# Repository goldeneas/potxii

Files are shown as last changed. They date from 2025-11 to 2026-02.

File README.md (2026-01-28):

# Progetto PotXII

## Interfaccia
- Dashboard NodeRED
- MQTT/Wifi
- Diagramma di linea per ogni grandezza misurata
- Grafico per indicare il livello dell'acqua nel tempo
- Log per eventi eccezionali
- Soglia umidita' per irrigazione
- Livello luminosita' dei LED regolabile
- Attivazione manuale pompa

## Sensori/Componenti Utilizzati
- Pompa ad immersione con rele'
- HCSR04
- Sensore per umidita' del terreno
- TSL2561
- SSD1306
- DHT
- Power supply esterno
- LED con PWM
- Pulsante per reset
- MB102

## Features
- Start at boot
- Notifica dashboard serbatoio vuoto
- Misurazione umidità terreno ed aria, luminosità e temperatura aria
- Analisi delle grandezze misurate
- Irrigazione automatica
- Illuminazione con LED

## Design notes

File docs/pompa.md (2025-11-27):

1. Il Circuito di Potenza (Batteria e Pompa)
Questo è il circuito che fa girare effettivamente l'acqua. Qui passa la corrente alta.

Usa le 3 viti (morsetti) del relè. Ignora "NC" (Normally Closed), useremo "NO" (Normally Open) perché vuoi che la pompa stia spenta finché non dai il comando.

    Batteria (+) [Positivo]: Collegalo al morsetto centrale COM del relè.

    Relè NO [Normally Open]: Collega qui il filo ROSSO del motore.

    Batteria (-) [Negativo]: Collega qui direttamente il filo NERO del motore.

Cosa succede fisicamente: La corrente parte dalla batteria, arriva al morsetto COM, si ferma perché l'interruttore è aperto. Quando il relè scatta, il contatto si chiude verso NO, la corrente fluisce nel filo rosso, attraversa il motore e torna alla batteria col filo nero.

2. Il Circuito di Controllo (I 3 Pin)

Qui è dove rischi di fare danni se non sai cosa stai facendo. Questi tre pin servono per dire al relè "accenditi".

    VCC: Qui devi dare l'alimentazione per la bobina del relè.

        Attenzione: Leggi cosa c'è scritto sul relè (es. 5V o 12V). Se il relè è da 5V e gli dai 12V dalla batteria della pompa, lo bruci. Se il relè è da 12V e la batteria è da 12V, puoi collegarlo al positivo della batteria.

    GND: Va al negativo (Ground) della batteria o del microcontrollore.

    IN: Questo è il segnale. Per accendere la pompa, questo pin deve ricevere un segnale (solitamente 5V o 3.3V se usi Arduino, oppure collegato a GND o VCC a seconda se il relè è "Low Trigger" o "High Trigger").

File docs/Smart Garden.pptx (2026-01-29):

## Smart Garden

Gruppo 12

## SMART POT-XII

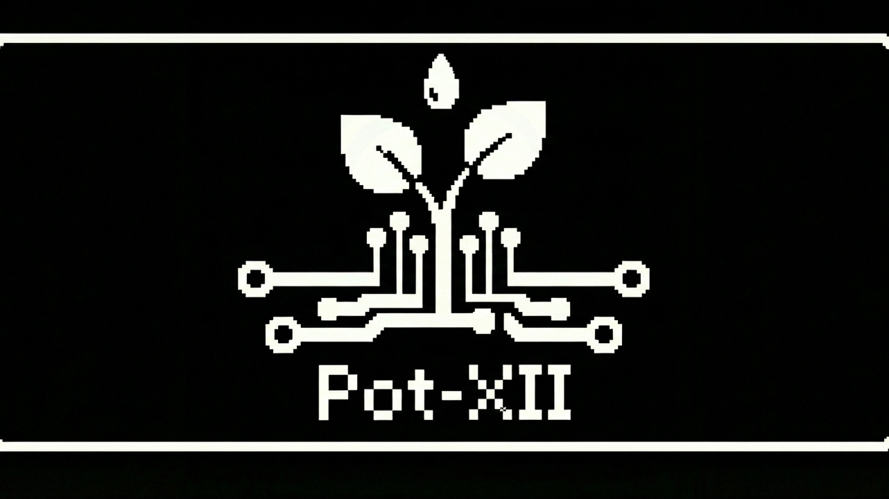
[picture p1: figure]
Immagine che contiene testo, Carattere, logo, simbolo Il contenuto generato dall'IA potrebbe non essere corretto.

Un sistema intelligente progettato per la cura automatizzata delle piante domestiche. Smart Pot-XII trasforma un normale vaso in un ecosistema monitorato.

Salute della pianta al primo posto
Tecnologia ESP32 integrata
Irrigazione automatica basata sui d

## SENSORE UMIDITA’ DEL TERRENO

Il sensore di umidità del terreno lavora insieme ad un Comparatore di tensione (quello blu).
La sonda a forma di forca, cioè il sensore, viene inserita nel terreno e invia un segnale di resistenza variabile al Comparatore di Tensione il quale lo trasforma in una tensione compresa tra 0V e 3,3V.
Quindi all'ESP32 arriva un segnale analogico (la tensione) attraverso il pin A0.
Dato che l’SP32 usa solo il linguaggio digitale, colleghiamo il pin A0 del Comparatore ad un pin ADC dell‘Espe32.
L’esp32 leggerà la tensione è la tradurrà in valori compresi tra 0 (massima umidità) e 4095(terreno secco)

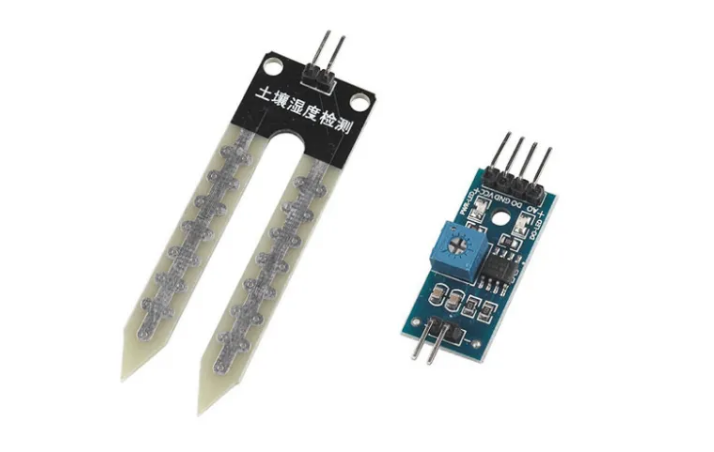
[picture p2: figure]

## SENSORE DELLA LUMINOSITA’

Il TSL2561 è un sensore digitale di luminosità.
Ha 4 pin: VCC (3.3V), GND, SCL, SDA.
Il TSL2561 comunica tramite il protocollo I2C, che richiede due pin fondamentali:
SCL (Serial Clock): È il segnale di clock che sincronizza la trasmissione dei dati.
SDA (Serial Data): È il pin su cui viaggiano fisicamente i dati digitali della luminosità.

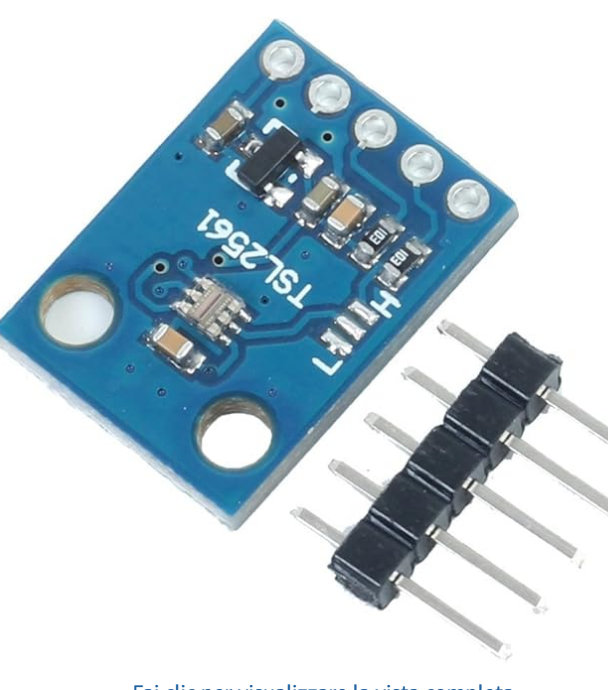
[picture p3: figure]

## SENSORE AD ULTRASUONI

Il Sensore di distanza ad ultrasuoni HCSR04
Ha 4 pin: VCC(3.3V), TRIG, ECHO, GND
La comunicazione con questo sensore avviene
attraverso un driver. Quando il pin TRIG e' alto, il sensore invia un segnale ad ultrasuoni a 40Hz; quando il segnale rimbalza su un oggetto e colpisce il sensore, il pin ECHO viene messo alto per il tempo di volo del segnale.
La formula per la conversione in distanza usa la velocita' del suono nell'aria (340 m/s):
distanza = tempo[s] * 340[m/s] / 2

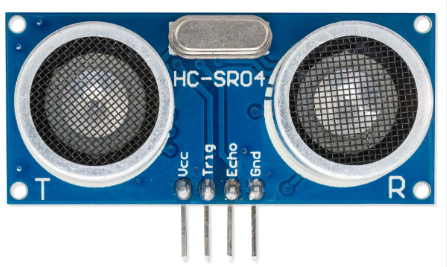
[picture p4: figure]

## POMPA

La pompa ad immersione
Viene utilizzata con una fonte di alimentazione esterna e con un rele'
Il rele' fornisce tre pin da collegare: VCC, GND e IN.
Possiamo attivare la pompa mantenendo alto il pin IN per il tempo richiesto.
Per il corretto funzionamento bisogna collegare la porta COM con l'alimentazione della pompa, e la porta NO (Normally Open) con l'alimentazione esterna.

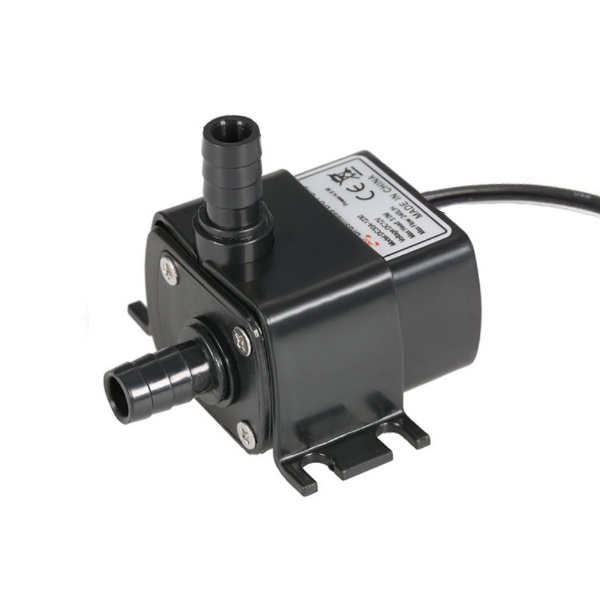
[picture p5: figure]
Mini pompa ad immersione 12 Vdc
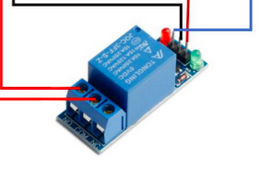
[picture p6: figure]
Immagine che contiene Componente di circuito, Ingegneria elettronica, Componente elettrico, Componente di circuito passivo Il contenuto generato dall&#39;IA potrebbe non essere corretto.

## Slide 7

DASHBOARD NODERED

La dashboard rappresenta il centro di controllo operativo permette di visualizzare i dati in tempo reale provenienti dall'ESP32 tramite l’utilizzo del protocollo MQTT.
Visualizzazione immediata della temperatura e dell’umidità dell'aria, dell’umidità del suolo, dell’esposizione alla luce e del livello del serbatoio.

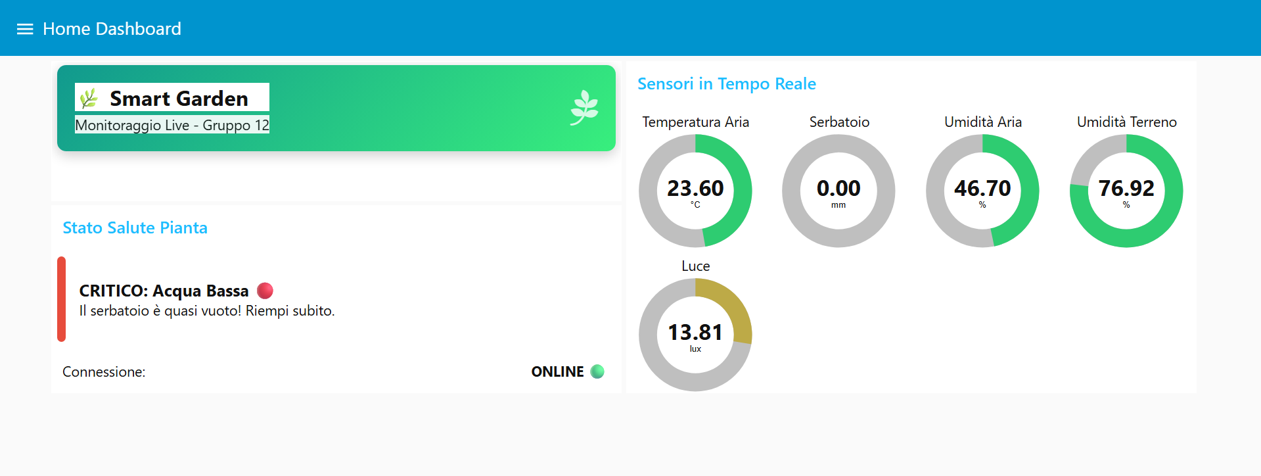
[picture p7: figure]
Immagine che contiene testo, schermata, Carattere, software Il contenuto generato dall'IA potrebbe non essere corretto.

Homepage

## DASHBOARD NODERED

Tramite la dashboard è possibile

Monitorare i grafici; diagrammi dedicati ad ogni grandezza fisica misurata
Gestire il serbatoio; prevedere quando bisogna riempire il serbatoio, attivare manualmente la pompa o impostare una soglia d’umidità per l’irrigazione automatica
Monitorare i log; registro per tracciare eventi particolare (attivazione pompa o livello d’acqua nel serbatoio)
Compensare la scarsa luce naturale (simulazione); slider per regolare l'intensità dei LED tramite PWM

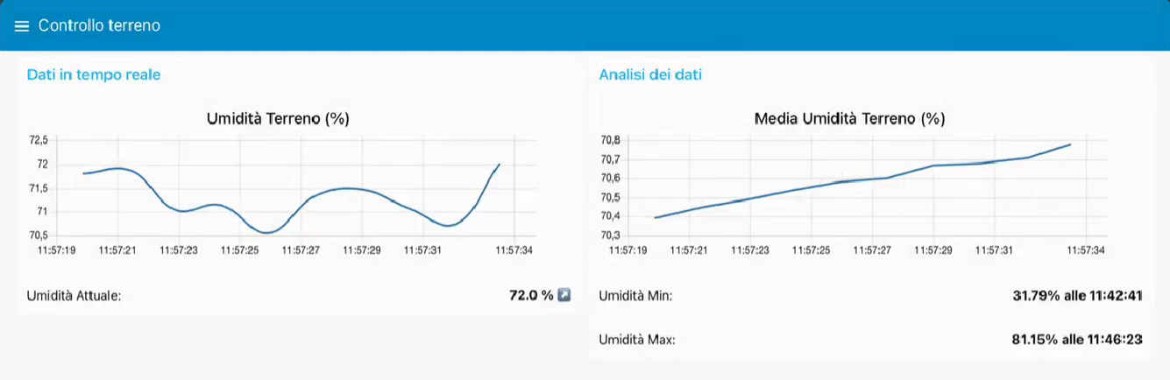
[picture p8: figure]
Immagine che contiene testo, schermata, linea, Diagramma Il contenuto generato dall'IA potrebbe non essere corretto.

Grafici in tempo reale

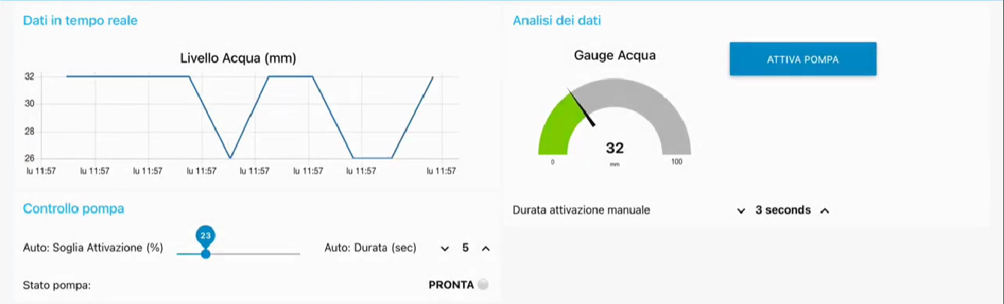
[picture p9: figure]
Immagine che contiene testo, diagramma, schermata, Carattere Il contenuto generato dall'IA potrebbe non essere corretto.

Gestione serbatoio

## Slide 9

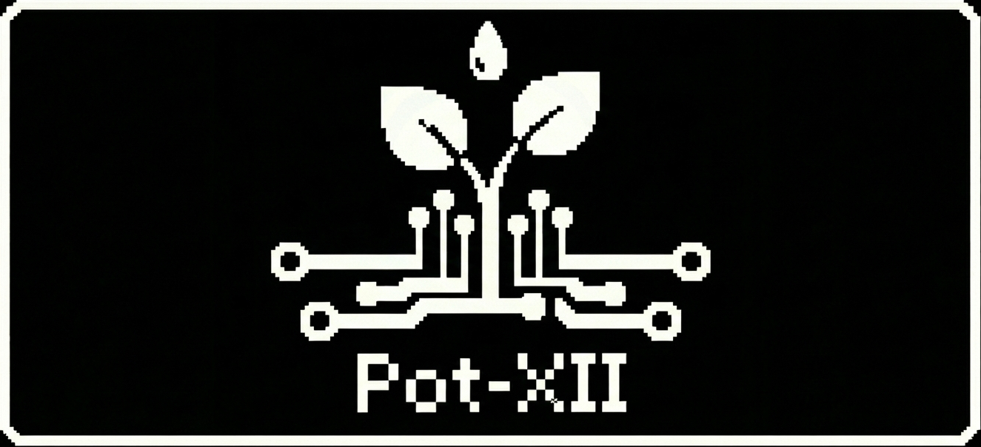
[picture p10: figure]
Immagine che contiene testo, Carattere, logo, simbolo Il contenuto generato dall'IA potrebbe non essere corretto.

Lisena Nicolò Massimo
Mancini Sofia
Picarella Nicola

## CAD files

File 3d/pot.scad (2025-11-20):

pot_width = 20;
pot_depth = 20;
pot_height = 10;

tank_width = 10;
tank_depth = 10;
tank_height = 10;

module hexagon() {
	cylinder(r=10, h=5, $fn=6);
}

module pot(position, dimensions) {
    diff_position = [for (i = position) i + 1];
        
    diff_dimensions = [
        for (i = [0 : 2])
            if(i == 2) dimensions[i]
            else dimensions[i] - 2
    ];
    
    difference () {
        translate(position) {
            cube(dimensions);
        }
        
        translate(diff_position) {
            cube(diff_dimensions);
        }
    }
}

module tank(position, dimensions) {
    translate([20, 10, 0]) {
        difference () {
            cylinder(7, 10, 10);
            translate([-10, 0, 9]) {
                cube(20, center = true);
            };
            translate ([0, 0, 1]) {
                cylinder(11, 9, 9);
            }
        }
    } 
}

module esp_container() {
    pot([0, pot_depth - 8, 0], [20, 8, 20]);
}

module holes() {
    translate([19.5, 15, 16]) {
        rotate([0, 90, 0]) {
            sphere(1.5);
        }
    }
	
	translate([8.5, 18.5, 15]) {
		cube([2.174, 1.806, 2]);
	}
	
	translate([13, 12.3, 15]) {
        rotate([0, 90, 0]) {
            sphere(1.5);
        }
    }
}

module lid() {
    union() {
        color ("red", 1.0) {
            translate ([0, 12, 30]) {
                cube([20, 8, 1]);
            }
        }
    
        color ("blue", 1.0) {
            translate ([1, 13, 29.5]) {
                cube([18, 6, 1]);
            }
        }
    }
}

module esp_plane() {
    translate([0, 12, 10]) {
		cube([20, 7, 1]);
    }
}

union () {
    difference() {
        tank([pot_width - 0.9, 5, 0], [tank_width, tank_depth, tank_height]);
        holes();
    }
    
    difference() {
        esp_container();
        holes();
    }
    
    difference() {
        pot([0, 0, 0], [pot_width, pot_depth, pot_height]);
        holes();
    }
	
	difference() {
        esp_plane();
        holes();
    }
}

lid();
 

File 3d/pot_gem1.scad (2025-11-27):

// ==============================================================================
// PROGETTO: All-in-One Smart Vase (ESP32 IoT)
// VERSIONE: 1.0.0
// MATERIALE CONSIGLIATO: PETG o ASA (Impermeabile, resistente UV)
// NOTE DI STAMPA: 
// - Pareti: Almeno 3 perimetri per impermeabilità.
// - Infill: 20% Gyroid.
// - Supporti: Minimi necessari solo per la finestra OLED o i passaggi cavi.
// ==============================================================================

// --- PARAMETRI GENERALI ---
$fn = 60; // Risoluzione curve (aumentare per export finale)
wall_thick = 3.0; // Spessore pareti (robusto per tenuta stagna)
tolerance = 0.4;  // Tolleranza per parti a incastro (vassoio)

// --- DIMENSIONI VASO ---
vase_width = 140;
vase_depth = 140;
vase_height = 150;
corner_radius = 10;

// --- DIMENSIONI ELETTRONICA ---
oled_width = 27;  // Larghezza modulo OLED 0.96
oled_height = 27; // Altezza modulo OLED (approssimativa del PCB)
oled_screen_w = 23; // Larghezza solo schermo
oled_screen_h = 12; // Altezza solo schermo
esp32_bay_depth = 30; // Profondità vano elettronica

// --- CONFIGURAZIONE RENDERING ---
// Imposta a 1 per vedere il vaso, 0 per nasconderlo
show_main_body = 1;
// Imposta a 1 per vedere il vassoio di drenaggio, 0 per nasconderlo
show_drainage_tray = 1;
// Imposta a 1 per vedere il coperchio elettronica (da stampare piatto), 0 nascondi
show_lid = 0; 


// ==============================================================================
// LOGICA DI COSTRUZIONE
// ==============================================================================

module rounded_cube(size, r) {
    hull() {
        translate([r, r, 0]) cylinder(h=size[2], r=r);
        translate([size[0]-r, r, 0]) cylinder(h=size[2], r=r);
        translate([size[0]-r, size[1]-r, 0]) cylinder(h=size[2], r=r);
        translate([r, size[1]-r, 0]) cylinder(h=size[2], r=r);
    }
}

module main_body() {
    difference() {
        // 1. CORPO SOLIDO ESTERNO
        rounded_cube([vase_width, vase_depth, vase_height], corner_radius);

        // 2. SCAVO COMPARTO SUOLO (Retro Sinistra - occupa 60% volume)
        // Lasciamo spazio sotto per il vassoio di drenaggio (altezza 20mm)
        translate([wall_thick, wall_thick, 25]) 
            cube([vase_width - wall_thick*2, vase_depth*0.65, vase_height]);

        // 3. SCAVO SERBATOIO ACQUA (Retro Destra/Laterale)
        // Isolato dal suolo tramite parete
        // In questo design, mettiamo l'acqua DIETRO il suolo o A LATO.
        // Facciamo una "L" shape o dividiamo: Suolo Davanti, Acqua Dietro?
        // Meglio: Suolo occupa 2/3 posteriori, Acqua e Elettronica davanti.
        
        // RIDEFINIZIONE LAYOUT INTERNO PER SEMPLICITÀ E ROBUSTEZZA:
        // A: SUOLO -> Grande rettangolo posteriore
        // B: ACQUA -> Cilindro/Rettangolo anteriore sinistro
        // C: ELETTRONICA -> Rettangolo anteriore destro
        
        // RESET SCAVI PRECEDENTI, PROCEDIAMO CON NUOVO LAYOUT
    }
}

// Ricostruzione con layout a blocchi per massima chiarezza
module smart_vase_final() {
    
    water_tank_width = (vase_width / 2) - wall_thick;
    electronics_width = (vase_width / 2) - wall_thick;
    front_compartment_depth = 40; 
    soil_depth = vase_depth - front_compartment_depth - (wall_thick * 3);
    tray_height = 20;
    floor_z = tray_height + wall_thick + 2; // Altezza pavimento comparti superiori

    difference() {
        // --- POSITIVO: Guscio Esterno ---
        rounded_cube([vase_width, vase_depth, vase_height], corner_radius);

        // --- NEGATIVO: Comparto SUOLO (A) ---
        // Occupa la parte posteriore
        translate([wall_thick, front_compartment_depth + wall_thick*2, floor_z])
            rounded_cube([
                vase_width - wall_thick*2, 
                soil_depth, 
                vase_height // Va fino in cima
            ], 5);

        // --- NEGATIVO: Comparto ACQUA (B) ---
        // Anteriore Sinistro
        translate([wall_thick, wall_thick, floor_z])
            cube([
                water_tank_width - wall_thick, 
                front_compartment_depth, 
                vase_height
            ]);

        // --- NEGATIVO: Comparto ELETTRONICA (C) ---
        // Anteriore Destro
        translate([water_tank_width + wall_thick*2, wall_thick, floor_z])
            cube([
                electronics_width - wall_thick, 
                front_compartment_depth, 
                vase_height
            ]);

        // --- NEGATIVO: Vano Vassoio Drenaggio (D) ---
        // Scavo passante sul fondo (solo posteriore sotto il suolo)
        translate([wall_thick, front_compartment_depth + wall_thick*2, wall_thick])
            cube([
                vase_width - wall_thick*2, 
                soil_depth + 10, // Un po' più lungo per estrazione
                tray_height
            ]);
            
        // --- DETTAGLI FUNZIONALI ---
        
        // 1. Fori di drenaggio (Suolo -> Vassoio)
        for(x = [20 : 15 : vase_width-20]) {
            for(y = [front_compartment_depth + 30 : 15 : vase_depth-20]) {
                translate([x, y, floor_z - 5])
                    cylinder(h=10, r=2); // Fori da 4mm
            }
        }

        // 2. Finestra OLED (Nel comparto Elettronica)
        translate([water_tank_width + wall_thick*2 + (electronics_width/2), -1, vase_height - 40]) {
            // Foro schermo passante
            cube([oled_screen_w, 10, oled_screen_h], center=true);
            // Scasso interno per il PCB (non passante)
            translate([0, 3, 0])
                cube([oled_width, 5, oled_height], center=true);
        }
        
        // 3. Passaggi Cavi (Cavidotti interni)
        // Elettronica -> Suolo (per sensori)
        translate([water_tank_width + wall_thick*2 + (electronics_width/2), front_compartment_depth - 5, vase_height - 20])
            rotate([90, 0, 0])
            cylinder(h=20, r=4); // Foro 8mm inclinato verso il suolo

        // Elettronica -> Acqua (per pompa)
        // Foro nel muro divisorio centrale
        translate([water_tank_width + wall_thick/2 + 1, front_compartment_depth/2, 40])
            rotate([0, 90, 0])
            cylinder(h=10, r=3, center=true);
            
        // 4. Foro USB (lato elettronica o fondo)
        translate([vase_width - 10, front_compartment_depth/2, floor_z + 10])
            rotate([0, 90, 0])
            cylinder(h=20, r=4); // Accesso cavo alimentazione laterale
    }
}

module drainage_tray() {
    tray_w = vase_width - wall_thick*2 - tolerance;
    front_compartment_depth = 40; 
    soil_depth = vase_depth - front_compartment_depth - (wall_thick * 3);
    tray_d = soil_depth;
    tray_h = 18;

    difference() {
        // Corpo vassoio
        cube([tray_w, tray_d, tray_h]);
        // Scavo interno vassoio
        translate([wall_thick, wall_thick, wall_thick])
            cube([tray_w - wall_thick*2, tray_d - wall_thick, tray_h]);
    }
    
    // Maniglia estrazione
    translate([tray_w/2, 0, tray_h/2])
        rotate([90,0,0])
        cylinder(h=5, r1=5, r2=8);
}

module electronics_lid() {
    // Semplice coperchio per chiudere sopra se necessario, 
    // anche se il design è open top per il suolo.
    // Creiamo un tappo solo per il vano elettronica per proteggerlo dagli schizzi
    
    water_tank_width = (vase_width / 2) - wall_thick;
    electronics_width = (vase_width / 2) - wall_thick;
    front_compartment_depth = 40; 
    
    cube([electronics_width - wall_thick - tolerance, front_compartment_depth - tolerance, 2]);
}

// ==============================================================================
// GENERAZIONE SCENA
// ==============================================================================

if (show_main_body) {
    color("Teal") 
    smart_vase_final();
}

if (show_drainage_tray) {
    front_compartment_depth = 40; 
    // Posizioniamo il vassoio nel suo alloggiamento
    color("Silver")
    translate([wall_thick + tolerance/2, front_compartment_depth + wall_thick*2, wall_thick])
        drainage_tray();
}

if (show_lid) {
    water_tank_width = (vase_width / 2) - wall_thick;
    // Posizionato sopra l'elettronica
    color("DarkSlateGray")
    translate([water_tank_width + wall_thick*2 + tolerance/2, wall_thick + tolerance/2, vase_height])
        electronics_lid();
}
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

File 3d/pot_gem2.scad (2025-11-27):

// ==============================================================================
// PROGETTO: All-in-One Smart Vase (ESP32 IoT)
// VERSIONE: 1.4.0 (Water Level Sensor Correction)
// ==============================================================================

// --- PARAMETRI GENERALI ---
$fn = 60;
wall_thick = 3.0; 
tolerance = 0.5; 

// --- DIMENSIONI VASO ---
vase_width = 200;
vase_depth = 200;
vase_height = 180;
corner_radius = 10;

// --- DIMENSIONI ELETTRONICA / COMPARTI ANTERIORI ---
oled_width = 24;  
oled_height = 16; 
oled_screen_w = oled_width; 
oled_screen_h = oled_height; 

esp32_bay_depth = 100; 

// --- CONFIGURAZIONE NUOVA: PAVIMENTO ELETTRONICA ---
electronics_floor_z = 80; 

inner_corner_radius = 6;

// --- CONFIGURAZIONE RENDERING ---
show_main_body = 1;
show_drainage_tray = 1;
show_lid = 0; 
show_sensor = 1; 

// ==============================================================================
// LOGICA DI COSTRUZIONE
// ==============================================================================

module lid_generic(w, d) {
    lid_h = 2;
    lid_r = max(1, inner_corner_radius - tolerance); 
    
    union() {
        rounded_cube([w, d, lid_h], lid_r);
        translate([w/2, d/2, lid_h])
            cylinder(h=5, r1=4, r2=6);
    }
}

module rounded_cube(size, r) {
    hull() {
        translate([r, r, 0]) cylinder(h=size[2], r=r);
        translate([size[0]-r, r, 0]) cylinder(h=size[2], r=r);
        translate([size[0]-r, size[1]-r, 0]) cylinder(h=size[2], r=r);
        translate([r, size[1]-r, 0]) cylinder(h=size[2], r=r);
    }
}

module smart_vase_final() {
    
    water_tank_width = (vase_width / 2) - wall_thick;
    electronics_width = (vase_width / 2) - wall_thick;
    
    front_compartment_depth = esp32_bay_depth; 
    
    soil_depth = vase_depth - front_compartment_depth - (wall_thick * 3);
    tray_height = 20;
    floor_z = tray_height + wall_thick + 2; 

    difference() {
        // --- POSITIVO: Guscio Esterno ---
        rounded_cube([vase_width, vase_depth, vase_height], corner_radius);

        // --- NEGATIVO: Comparto SUOLO (A) ---
        translate([wall_thick, front_compartment_depth + wall_thick*2, floor_z])
            rounded_cube([
                vase_width - wall_thick*2, 
                soil_depth, 
                vase_height 
            ], 5);

        // --- NEGATIVO: Comparto ACQUA (B) ---
        translate([wall_thick, wall_thick, floor_z])
            rounded_cube([
                water_tank_width - wall_thick, 
                front_compartment_depth, 
                vase_height
            ], inner_corner_radius);

        // --- NEGATIVO: Comparto ELETTRONICA (C) ---
        translate([water_tank_width + wall_thick*2, wall_thick, electronics_floor_z])
            rounded_cube([
                electronics_width - wall_thick, 
                front_compartment_depth, 
                vase_height 
            ], inner_corner_radius);

        // --- NEGATIVO: Vano Vassoio Drenaggio (D) ---
        translate([wall_thick, front_compartment_depth + wall_thick*2, wall_thick])
            rounded_cube([
                vase_width - wall_thick*2, 
                soil_depth + 20, 
                tray_height
            ], inner_corner_radius);
            
        // --- DETTAGLI FUNZIONALI ---
        
        // 1. Fori di drenaggio
        for(x = [20 : 20 : vase_width-20]) {
            for(y = [front_compartment_depth + 30 : 20 : vase_depth-20]) {
                translate([x, y, floor_z - 5])
                    cylinder(h=10, r=2.5); 
            }
        }

        // 2. Finestra OLED
        translate([water_tank_width + wall_thick*2 + (electronics_width/2), -1, vase_height - 40]) {
            cube([oled_screen_w, 10, oled_screen_h], center=true);
            translate([0, 3, 0])
                cube([oled_width, 5, oled_height], center=true);
        }
        
        // 3. Passaggi Cavi
        // Elettronica -> Suolo
        translate([water_tank_width + wall_thick*2 + (electronics_width/2) - 15, front_compartment_depth - 5, vase_height - 25])
            rotate([-90, 0, 0]) 
            cylinder(h=25, r=10); 

        // Elettronica -> Acqua (Sensore Livello / Pompa)
        // Questo foro collega la parte alta del serbatoio con la parte alta dell'elettronica
        translate([water_tank_width + wall_thick*1.5, front_compartment_depth/2, vase_height - 20])
            rotate([0, 90, 0])
            cylinder(h=wall_thick*4, r=10, center=true);
            
        // 4. Foro USB 
        translate([vase_width - 10, front_compartment_depth/2, electronics_floor_z + 15])
            rotate([0, 90, 0])
            cylinder(h=20, r=10); 
            
        // 5. Foro Tubo Acqua
        translate([water_tank_width + wall_thick*2 + (electronics_width/2) + 15, front_compartment_depth - 5, vase_height - 25])
            rotate([-90, 0, 0])
            cylinder(h=25, r=10);
    }
}

module drainage_tray() {
    front_compartment_depth = esp32_bay_depth; 
    
    tray_w = vase_width - wall_thick*2 - tolerance;
    soil_depth_actual = vase_depth - front_compartment_depth - (wall_thick * 2); 
    tray_d = soil_depth_actual - 5; 
    tray_h = 20 - tolerance; 

    difference() {
        cube([tray_w, tray_d, tray_h]);
        translate([wall_thick, wall_thick, wall_thick])
            cube([tray_w - wall_thick*2, tray_d - wall_thick*2, tray_h + 10]);
    }
    
    translate([tray_w/2, 0, tray_h/2]) {
        difference() {
            union() {
                translate([0, -2, 0]) cube([30, 4, tray_h], center=true);
                rotate([90,0,0]) cylinder(h=2, r=8);
            }
            rotate([90,0,0]) cylinder(h=10, r=4, center=true);
        }
    }
}

module electronics_lid() {
    water_tank_width = (vase_width / 2) - wall_thick;
    electronics_width = (vase_width / 2) - wall_thick;
    front_compartment_depth = esp32_bay_depth; 
    
    cube([electronics_width - wall_thick - tolerance, front_compartment_depth - tolerance, 2]);
}

module us_support() {
    // Dimensioni standard HC-SR04 approssimative
    us_pcb_w = 45; 
    us_pcb_h = 20;
    
    holder_w = esp32_bay_depth;
    holder_d = 10; 
    holder_h = 40; // Leggermente più compatto
    
    holes_radius = 8.2;
	
	rotate([90, 0, 90]) {
		translate([-37.5, 30, -17]) {
			translate([0, -10, holder_h - 5]) {
				cube([esp32_bay_depth, 10, 5]);
			}

			difference() {
				// Corpo principale
				cube([holder_w, holder_d, holder_h]);
				
				// Scasso PCB
				translate([(holder_w - us_pcb_w)/2, 2, (holder_h - us_pcb_h)/2 + 2])
					cube([us_pcb_w, holder_d, us_pcb_h]);
					
				// Fori occhi (passanti)
				translate([holder_w/2, -1, (holder_h/2)]) {
					translate([-13, 0, 0]) rotate([-90,0,0]) cylinder(h=holder_d+2, r=holes_radius);
					translate([13, 0, 0]) rotate([-90,0,0]) cylinder(h=holder_d+2, r=holes_radius);
				}
			}
		}
	}
}

// ==============================================================================
// GENERAZIONE SCENA
// ==============================================================================

if (show_main_body) {
    color("Teal", 0.8) 
    smart_vase_final();
}

if (show_sensor) {
    // LOGICA DI POSIZIONAMENTO CORRETTA PER LIVELLO ACQUA
    // Deve stare sopra il comparto ACQUA, puntando GIÙ (-Z)
    
    water_tank_w = (vase_width / 2) - wall_thick;
    
    // Posizione X: Centrato nel comparto acqua
    sens_x = wall_thick + (water_tank_w/2) - (55/2); // 55 è width del supporto
    
    // Posizione Y: Centrato in profondità
    sens_y = wall_thick + (esp32_bay_depth/2) - (25/2); // 25 è (ora) height del supporto che diventa profondità ruotato
    
    // Posizione Z: In cima al vaso, appena sotto il bordo
    sens_z = vase_height;

    color("Gold")
    translate([sens_x + 55, sens_y, sens_z - 20]) // Aggiustamenti fini per rotazione
        rotate([0, 180, 0]) // Capovolto a testa in giù (cavi in alto, occhi in basso)
        us_support();
}

if (show_drainage_tray) {
    front_compartment_depth = esp32_bay_depth; 
    color("Silver")
    translate([wall_thick + tolerance/2, front_compartment_depth + wall_thick*2 + 2, wall_thick])
        drainage_tray();
}

if (show_lid) {
    water_tank_width = (vase_width / 2) - wall_thick;
    electronics_width = (vase_width / 2) - wall_thick;
    lid_w_water = water_tank_width - wall_thick - tolerance;
    lid_w_elec = electronics_width - wall_thick - tolerance;
    lid_d = esp32_bay_depth - tolerance;
    
    color("DarkSlateGray") {
        translate([wall_thick + tolerance/2, wall_thick + tolerance/2, vase_height])
            lid_generic(lid_w_water, lid_d);
            
        translate([water_tank_width + wall_thick*2 + tolerance/2, wall_thick + tolerance/2, vase_height])
            lid_generic(lid_w_elec, lid_d);
    }
}

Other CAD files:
3d/pot_gem3.scad

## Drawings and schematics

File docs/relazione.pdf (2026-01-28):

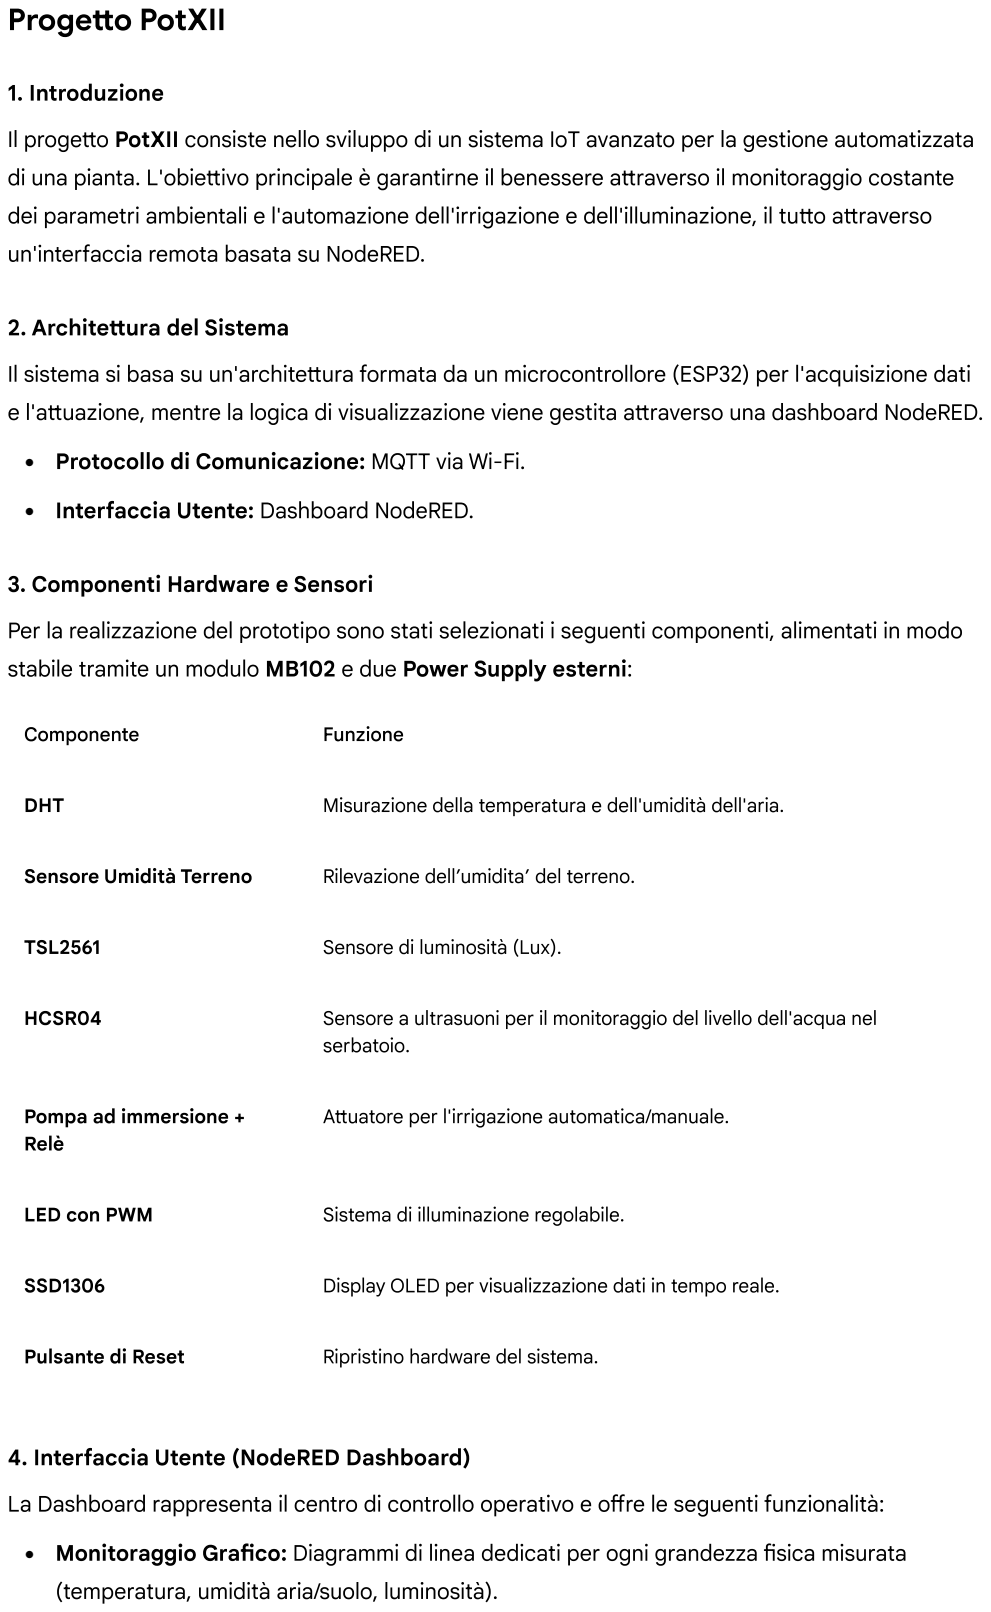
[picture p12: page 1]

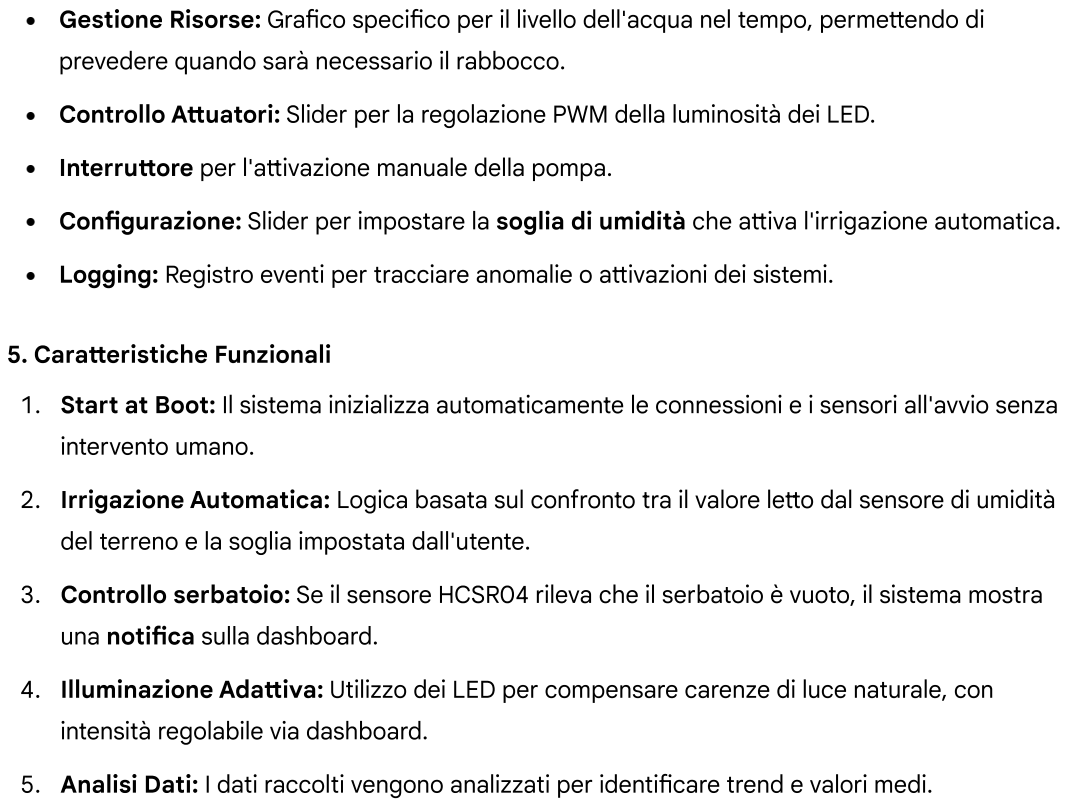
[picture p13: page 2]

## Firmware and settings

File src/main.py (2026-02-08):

from hcsr04 import HCSR04
from home_screen import HomeScreen
from humidity import Humidity
from pump import Pump
from three_led import ThreeLedPWM
from wifi import Wifi
from micro_mqtt import MicroMQTT
from ssd1306 import SSD1306_I2C
from machine import I2C
from dht import DHT22
from tsl2561 import TSL2561
import time

i2c = I2C(scl=22, sda=21)
display = SSD1306_I2C(128, 64, i2c);
wifi = Wifi(display);
mqtt = MicroMQTT("potxii", display);

display.draw_logo()
display.show()
time.sleep(3)

wifi.connect()

def mqtt_handler(topic, msg):  
    global pump
    global leds

    if (topic == "pot/water/pump"):
        time_s = int(msg)
        pump.on_for(time_s)
        print("Ho ricevuto secondi: " + str(time_s))

    if (topic == "pot/light/led"):
        led_perc = int(msg)
        leds.set_brightness(led_perc)
        print("Ho ricevuto un valore per i led di: " + str(led_perc))

mqtt.set_handler(mqtt_handler)

mqtt.connect("broker.hivemq.com", 1883, None, None)

#topic per dht
mqtt.subscribe("pot/air/temperature")
mqtt.subscribe("pot/air/humidity")

#topic per humidity
mqtt.subscribe("pot/ground/humidity")

#topic per hcsr04 e pompa
mqtt.subscribe("pot/water/water_level")
mqtt.subscribe("pot/water/pump")

#topic per tsl2561
mqtt.subscribe("pot/light/light_level")
mqtt.subscribe("pot/light/led")

#topic per wifi
mqtt.subscribe("pot/system/wifi")

#importiamo i pin 
hcsr04 = HCSR04(17,4)
dht = DHT22(15)
leds = ThreeLedPWM(32,33,25) 
tsl2561 = TSL2561(i2c)
humidity = Humidity(35)
pump = Pump(23)

home_screen = HomeScreen(hcsr04, mqtt, display, wifi, dht, tsl2561, humidity)

while True:
    mqtt.check_msg()
    
    home_screen.measure()
    home_screen.show()
    #time.sleep_ms(500)

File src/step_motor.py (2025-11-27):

# Serve 5V!!
import utime
from machine import Pin

class Stepmotor:
    def __init__(self, pin_id1, pin_id2, pin_id3, pin_id4):
        self.IN1 = Pin(pin_id1, Pin.OUT)
        self.IN2 = Pin(pin_id2, Pin.OUT)
        self.IN3 = Pin(pin_id3, Pin.OUT)
        self.IN4 = Pin(pin_id4, Pin.OUT)

        self.step_index = 0
        self._stepper_pins = [self.IN1, self.IN2, self.IN3, self.IN4]


        # full-step con 2 bobbine attive per ogni step
        # due bobbine accese per ogni step -> più coppia
        #il valore (0=spento, 1=acceso) da dare a quel pin nel passo corrente.
        self._step_sequence = [
            [1, 0, 0, 1], 
            [1, 1, 0, 0], 
            [0, 1, 1, 0], 
            [0, 0, 1, 1], 
        ]
        
        #la half-step corrispondente (8 stati) è questa:
        # Half-step (mezzo passo): alterna 1 bobina e 2 bobine
        self._step_sequence_half = [
            [1,0,0,0],
            [1,0,0,1],
            [0,0,0,1],
            [0,0,1,1],
            [0,0,1,0],
            [0,1,1,0],
            [0,1,0,0],
            [1,1,0,0],
        ]


    #direction = +1 (antiorario), -1 (orario)
    #steps = numero di passi da eseguire. max 2048
    #delay = tempo tra un passo e l'altro. tra 0.1, 0.01 e 0.005
    #step_index tiene traccia della posizione corrente nella sequenza di attivazione (fase) del motore.
    
    def step(self, direction, steps, delay):
        step_sequence = self._step_sequence
        stepper_pins = self._stepper_pins
        step_index = self.step_index

        for i in range(steps):
            # l'operatore % garantisce che step_index rimanga all'interno dell'intervallo valido (in questo caso [0-3]),
            # assicurando che la sequenza dei passi venga ripetuta ciclicamente.
            # indica la riga quindi quale passo
            step_index = (step_index + direction) % len(step_sequence) # se la sequenza ha 4 stati è come fare mod 4
    
            #pin_index determina la colonna (quindi la bobbina)
            for pin_index in range(len(stepper_pins)):
                #Esempio: se step_index = 2, la sequenza è [0, 1, 1, 0]
                # Se pin_index = 0 → pin_value = 0
                # Se pin_index = 1 → pin_value = 1
                # Se pin_index = 2 → pin_value = 1
                # Se pin_index = 3 → pin_value = 0
                pin_value = step_sequence[step_index][pin_index]
                #Scrive il valore sul pin fisico, accendendo o spegnendo la bobina
                stepper_pins[pin_index].value(pin_value)
    
            #Aspetta il tempo delay prima di passare al prossimo passo.
            #Pausa più corta → motore più veloce. Pausa più lunga → motore più lento.
            utime.sleep(delay)

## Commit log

2025-11-06 added defaults to servo
2025-11-06 added ledpwm, fix freq servo
2025-11-06 fix ledpwm float to int
2025-11-11 added step motor
2025-11-11 added comment to step motor
2025-11-11 fix step motor class
    [step_motor.py]
2025-11-11 fix step motor spacing
    [step_motor.py]
2025-11-11 ledpwm set brightness on init
2025-11-16 Inserimento logo e modifica classe ssd1306 con aggiunta di draw_logo e modifica draw_image
2025-11-17 added .scad for pot 3d model
    [pot.scad]
2025-11-17 added esp support to 3d model
    [pot.scad]
2025-11-17 added display hole
    [pot.scad]
2025-11-18 new pot smaller
    [pot.scad]
2025-11-20 fix tab in draw_image
    [ssd1306.py]
2025-11-20 change framebuffer to MONO_HLSB
2025-11-20 fixed ssd1306?
    [pot.scad]
2025-11-21 new 3d models
    [pot_gem1.scad, pot_gem2.scad]
2025-11-22 shorter esp32 bay
    [pot_gem2.scad]
2025-11-24 added holes for US sensor
    [pot_gem2.scad]
2025-11-25 added us sensor
    [pot_gem2.scad]
2025-11-25 better lids + corners
    [pot_gem2.scad]
2025-11-25 changed 3d model
    [pot_gem2.scad]
2025-11-27 added 3d model with us sensor holder
    [pot_gem3.scad]
2025-11-27 added build to gitignore
    [pot_gem3.scad]
2025-11-27 pump class
    [pot_gem3.scad]
2025-11-27 moved files to src directory + added warning_screen.py
    [pot_gem3.scad]
2025-11-28 Create CARATTERISTICHE SENSORE DI UMIDITA .txt
2025-11-30 MQTT added print on oled
2025-12-02 Updated pump.py and test_pump.py
2025-12-03 aggiunta la classe e il test umidità
2025-12-06 added tsl2561 driver
2025-12-09 changed tsl2561 driver
2025-12-09 aggiunto calcolo del trend pre temperature e umidità
2025-12-10 creata la classe per i 3 led
2025-12-10 Aggiunto il test del Sensore a ultrasuoni
2025-12-10 Modificata la classe dei 3 led
2025-12-10 aggiunta test per i 3 led
2025-12-10 modifiche classi sull'esp32
2025-12-12 cambiato pin umidità del terreno
2025-12-12 boot invece di main
2025-12-16 Aggiunta logica per usare lo slider come valore di soglia
2025-12-19 water elvel 116 mm
2025-12-19 added leds implementation
2025-12-22 modifica pin della pompa da 23 a 26
2026-01-28 Agiunta sezione per la dashboard nel pptx
2026-01-28 feat: added pump, hcsr04 to powerpoint
